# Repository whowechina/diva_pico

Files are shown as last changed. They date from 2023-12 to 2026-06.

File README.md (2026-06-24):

# Diva Pico - Project Diva Style Mini Controller
[点这里可以切换到中文版](README_CN.md)

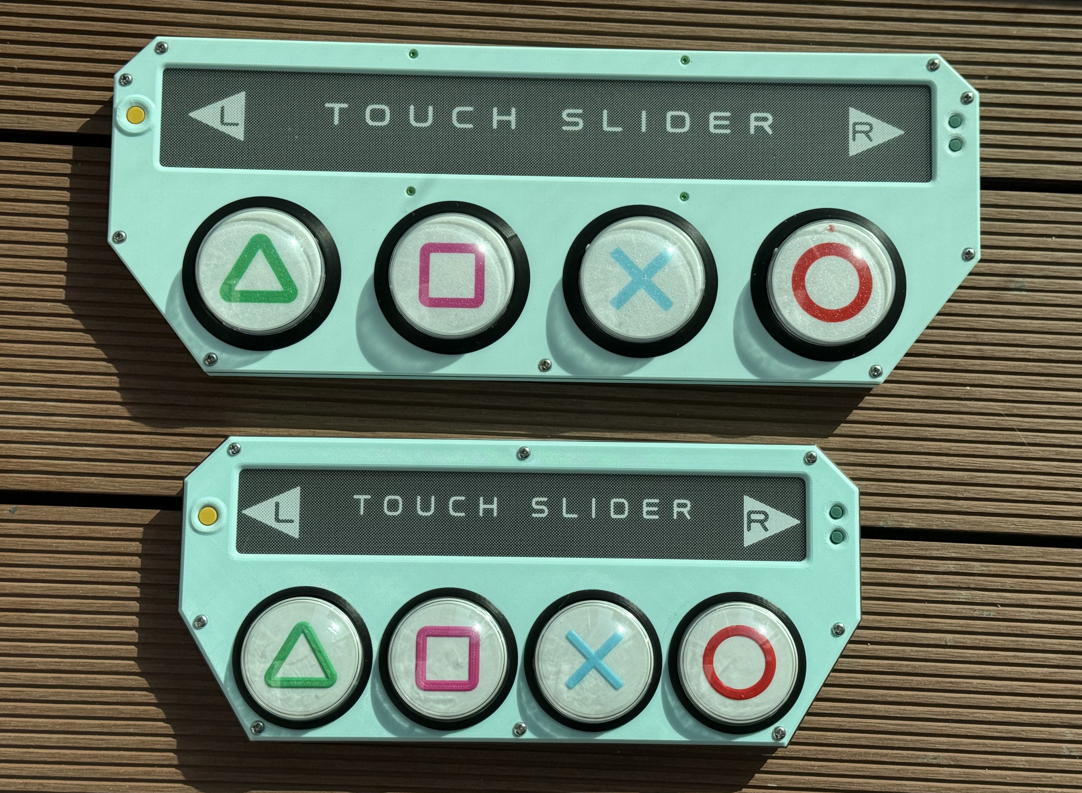
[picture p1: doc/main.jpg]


Features:
* Two sizes, Diva Pico and Diva Pico+.
* It's small, but the buttons are still decent.
* Support Nintendo Switch, Steam PC and Arcade version.
* HID light for Arcade version.
* All source files open.

Thanks to many respectful guys/companies who made their tools or materials free or open source (KiCad, OnShape, InkScape, Raspberry things).

Special thanks to community developers that inspired me and helped me: CrazyRedMachine (https://github.com/CrazyRedMachine).

And also:
* GP2040-CE: https://gp2040-ce.info/ (for the PS4 support)
* RP_Silicon_KiCad: https://github.com/HeadBoffin/RP_Silicon_KiCad
* Switch_Keyboard_Kailh: https://github.com/kiswitch/keyswitch-kicad-library

## Notes
This Diva Pico project:  
* Heavily depends on 3D printing, you need a Bambu 3D printer (X1, P1 or A1, not the mini version).
* Requires skills to solder tiny components.

## My Other Projects
You can check out my other cool projects.

               


* Popn Pico: https://github.com/whowechina/popn_pico
* IIDX Pico: https://github.com/whowechina/iidx_pico
* Chu Pico: https://github.com/whowechina/chu_pico
* Mai Pico: https://github.com/whowechina/mai_pico
* Diva Pico: https://github.com/whowechina/diva_pico
* AIC Pico: https://github.com/whowechina/aic_pico
* Groove Pico: https://github.com/whowechina/groove_pico
* Geki Pico: https://github.com/whowechina/geki_pico
* Musec Pico: https://github.com/whowechina/musec_pico
* Ju Pico: https://github.com/whowechina/ju_pico
* Bishi Pico: https://github.com/whowechina/bishi_pico
* Nos Pico: https://github.com/whowechina/nos_pico
* Voltex Pico: https://github.com/whowechina/voltex_pico
* Chord Pico: https://github.com/whowechina/chord_pico
* Dance Pico: https://github.com/whowechina/dance_pico
* Arcade Pico: https://github.com/whowechina/arcade_pico

## **Disclaimer** ##
I made this project in my personal time with no financial benefit or sponsorship. I will continue to improve the project. I have done my best to ensure that everything is accurate and functional, there's always a chance that mistakes may occur. I cannot be held responsible for any loss of your time or money that may result from using this open source project. Thank you for your understanding.

## About the License
It's CC-NC. So DIY for yourself and for your friend, don't make money from it. And plagiarism that doesn’t even dare to mention the original author is not acceptable. Plase note that pooling orders and group buying for raw materials is acceptable. Selling off any leftover components without profit is also acceptable.

If you're interested in some kind of commercial use, please contact me (Discord, QQ group, Wechat group or leave your contact in issue section).

## My Discord Invitation
https://discord.gg/M8f2PPQFEA

## HOW TO BUILD
### Frequently Made Mistakes
Many DIY enthusiasts commonly make certain mistakes during the building process. Please proceed with extra caution to avoid these.
* **MISTAKE: Soldering everything together without conducting intermediate testing.**  
  Remember, even professional engineers can make mistakes. It becomes significantly harder to identify the root cause of a problem when all components are already assembled or soldered. Therefore, it's advisable to solder and test in stages. The firmware is designed to function correctly even with some components missing, which is good for testing.
* **MISTAKE: Neglecting to cut the ADDR pin trace on the MPR121 module.**  
  The MPR121 module in the market has the ADDR pin pre-connected to ground. But the board expects a floating ADDR pin, otherwise the ADDR pin will short the circuit. Please verify your "CUT" using a multimeter.
* **MISTAKE: Rushing to replace components when something fails.**  
  Sometimes people prematurely assumes that the Raspberry Pi Pico or other modules are faulty.
  Be aware that desoldering and soldering large SMD components is a challenging task. It carries the risk of damaging the component or the PCB board. Patience and caution are crucial. Look at the schematics and PCB design files and ask help from community first. Questioning the integrity of these components should be your last resort.

### PCB
* Choose a PCB vendor (such as JLCPCB) and place an order with the gerber zip file (latest `Production\PCB\diva_xxx_xxx.zip`), regular FR-4 board, black color, thickness is **1.6mm**.  
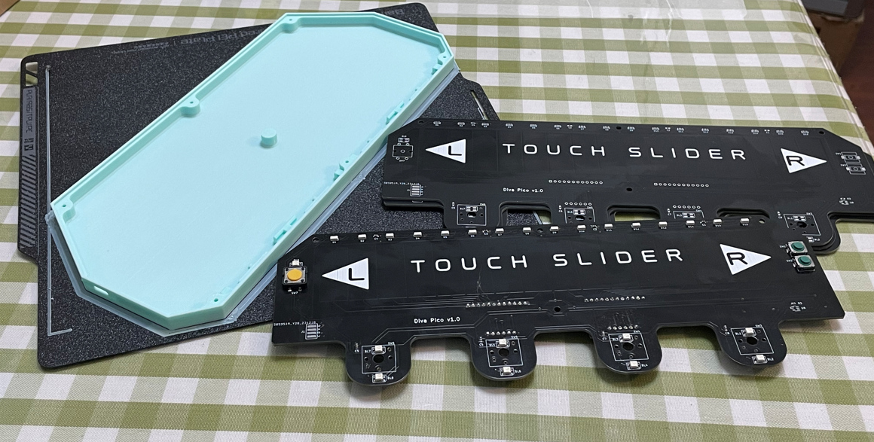
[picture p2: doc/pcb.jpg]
  

* 1x Rasberry Pico Pi Pico or **pin-to-pin** compatible clones.  
  https://www.raspberrypi.com/products/raspberry-pi-pico  
  Sticking a thin scotch tape to avoid short-circuit is a good idea.  
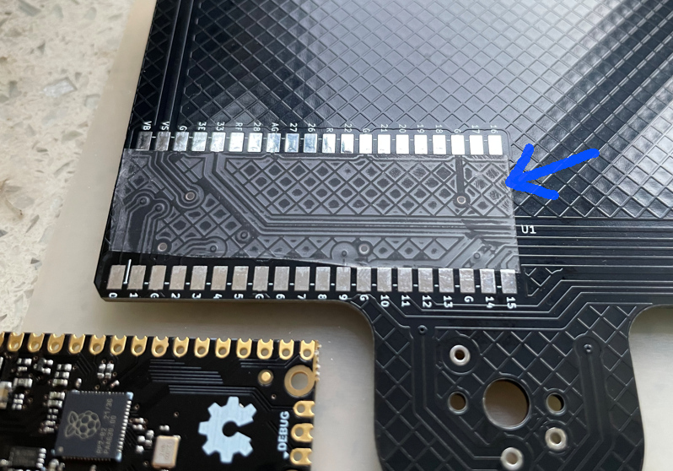
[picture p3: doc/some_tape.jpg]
  

* 16x WS2812B-4020 (32x for Diva Pico+) side-facing RGB LEDs for the slider.  
  https://www.lcsc.com/product-detail/Light-Emitting-Diodes-LED_Worldsemi-WS2812B-4020_C965557.html
* 9x WS2812B-3528 RGB LEDs for Diva Pico buttons. For Diva Pico+, you need 17x WS2812B-3528 reverse mount RGB LEDs.

* 2x MPR121 modules (3x for Diva Pico+), there're many types in the market, choose ones like this.  
  https://www.sparkfun.com/products/retired/9695  
  Before solder MP121 module to the main PCB board, remember to use a knife to **cut (unshort) the tiny trace that connects ADDR to the GND**. You can cut the red part as shown in the image. Please be careful not to cut more than necessary.  
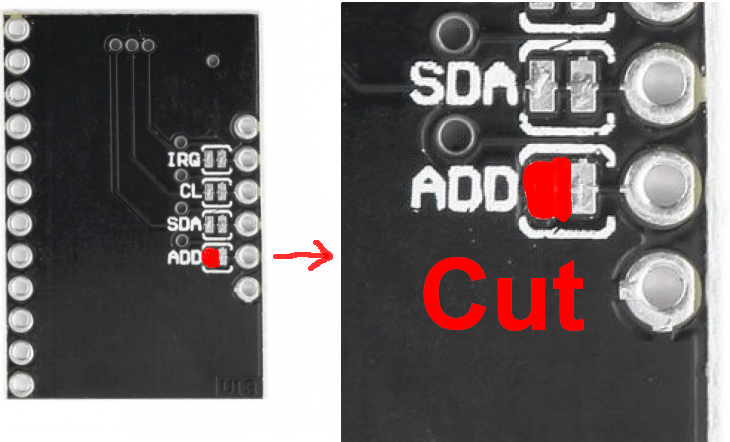
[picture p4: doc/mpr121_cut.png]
    

* 8x 0603 1uF (0.1~1uF all fine) capacitors (C1 to C8), OPTIONAL, recommended.

* 4x Kailh choc v1 switches, dark yellow is recommeded for its 70gf force.  
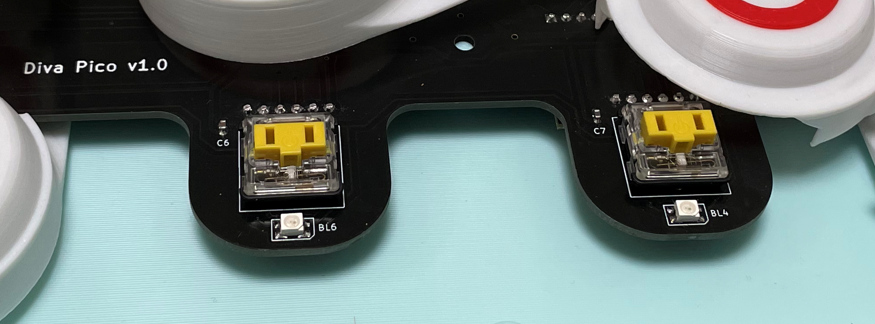
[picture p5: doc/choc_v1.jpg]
  

* 2x Alps SKSTAAE010 tactile switches.
  https://tech.alpsalpine.com/e/products/detail/SKSTAAE010/

* 1x Omron B3F-4005 or B3F-4000 micro-switch.
  https://www.mouser.com/ProductDetail/Omron-Electronics/B3F-4000?qs=B3tblJ0Nlt8c5sbFRctxww%3D%3D

* For Diva Pico only, 3M 5423 or 5421 UHMW PE film tape, important for button feel. 5423 is better for its thickness.  
  https://www.3m.com/3M/en_US/p/d/b40069119/

  You need to apply tapes to the contact surface of button to switch and button to base clamp.  
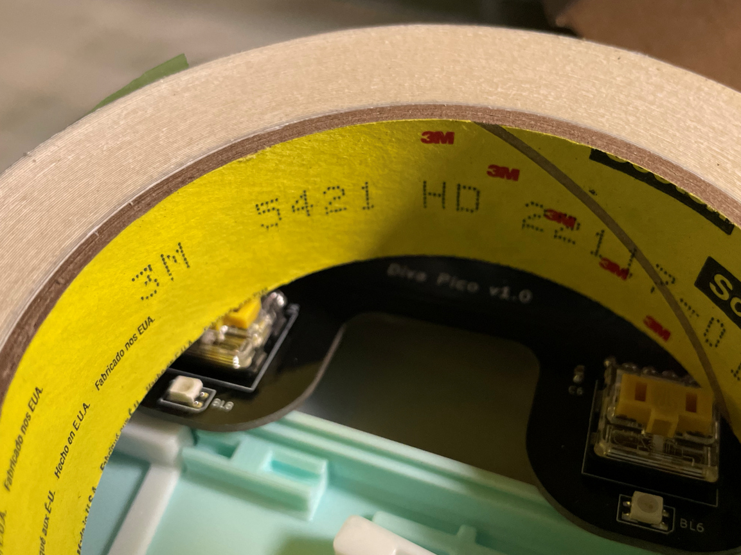
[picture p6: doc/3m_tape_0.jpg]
  
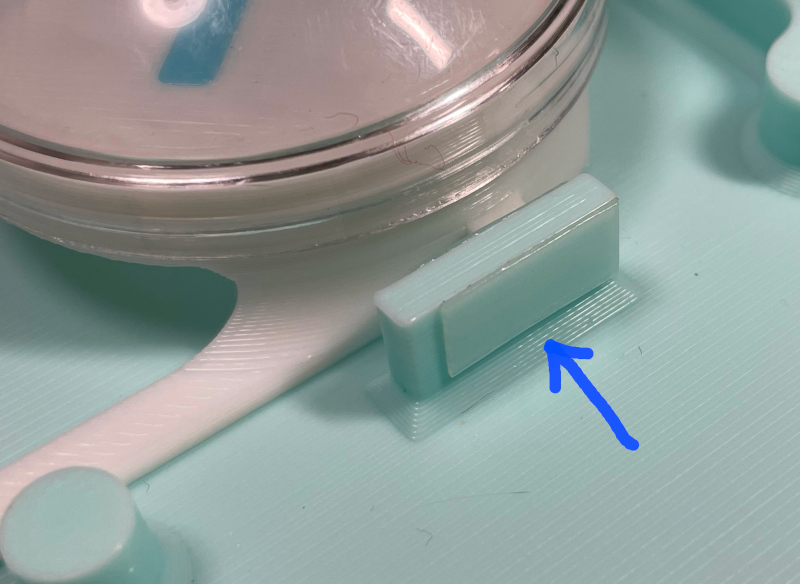
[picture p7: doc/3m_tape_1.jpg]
  
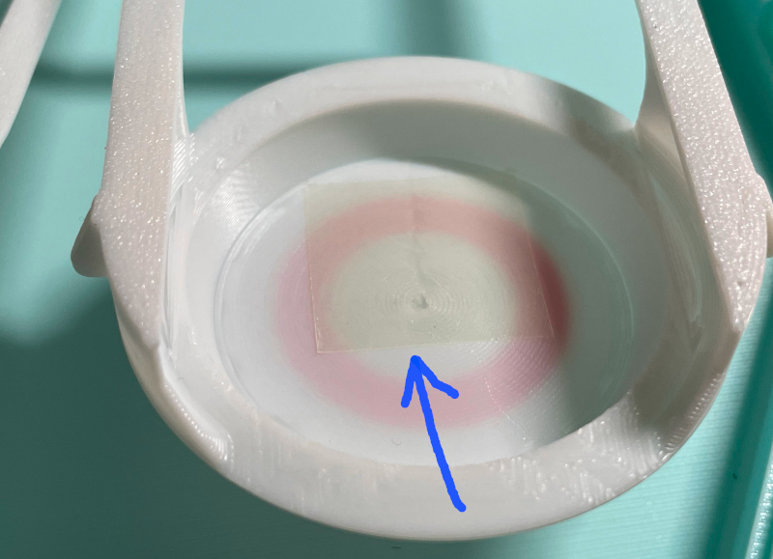
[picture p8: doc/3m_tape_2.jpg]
  

* For Diva Pico only, 4x 2mm\*50mm (diameter\*length) steel rods for the button lever structure.

* For Diva Pico+ only, 8x U-shape 2U stabilizer steel wires, you can also harvest them from regular 2U MX stabilizers. I invented this structure originally in my Voltex Pico project, checkout Voltex Pico repository for more details.

* For Diva Pico+ only, 4x 3mm\*5mm\*10mm regular springs for increasing the button force.

### Light Guide Panel
* Find a service to cut a light guide panel or a frosted acrylic panel. It's a perfect rectangle, 1.8mm to 2.0mm thickness
  * For Diva Pico, the size is 240mm\*42mm.
  * For Diva Pico+, the size is 329mm\*47mm.
* This is what a decent light guide panel looks like.  
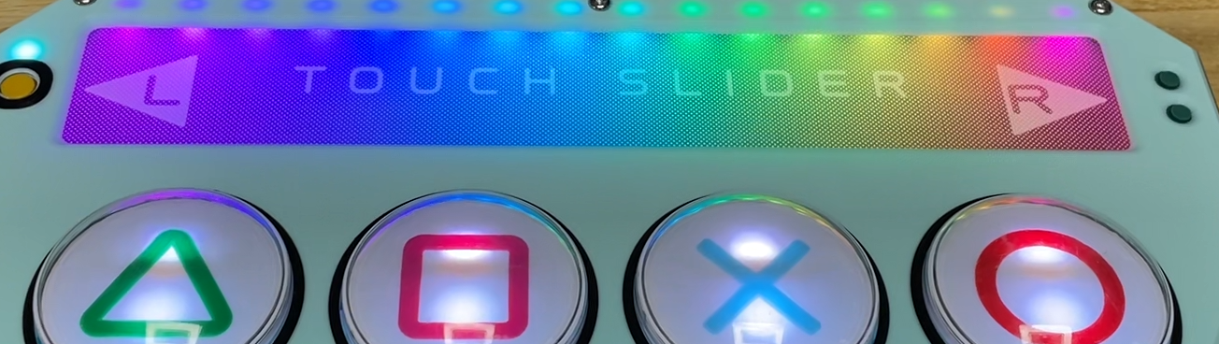
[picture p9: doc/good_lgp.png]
  

### 3D Printing
* You might need a Bambu 3D printer:
  *  For Diva Pico, a 256\*256mm bed is fine; for Diva Pico+ you need a H2D-sized bed.
  * Its AMS system works great for multi-color printing.
* Printing parameters  
  * PLA, PETG, ABS are all OK.
  * The color "Arctic Whisper" works best for the main body.
  * Layer height: 0.2mm
  * Support: Yes, always.

* Base: `Production\3D\diva_xxx_base.stl`.
* Cover Base: `Production\3D\diva_xxx_support.stl`.
* Cover: `Production\3D\diva_xxx_panel.3mf`, with multi-color support.
* Buttons: `Production\3D\diva_xxx_button_combo.3mf`, with multi-color support.  
  Note that button components (the button body, the seat and the logos on it) are mixed in one file, you need to cherry-pick before printing.  
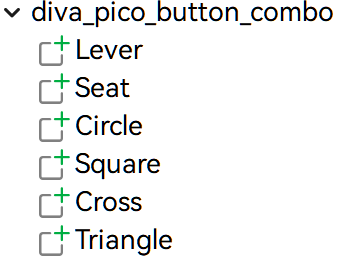
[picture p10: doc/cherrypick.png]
  

From top to bottom:
* Cover
* Cover Base + Light Guide Panel
* Buttons
* PCB
* Base

For Diva Pico, you need **6x M3*10mm regular screws** to fix all things. For Diva Pico+, you need **9x M3\*8mm** regular screws and **4x M2\*8mm** flat head screws.

Apply some 10mm\*2mm silicone anti-slip pads to the bottom side of the base to provide stability when playing.  

#### Button dome choices
* Go buy 60mm dome buttons.
  * For Diva Pico+, a regular 60mm arcade dome button is fine.
  * For Diva Pico, you should get this specific one, its inner diameter is 46mm.  
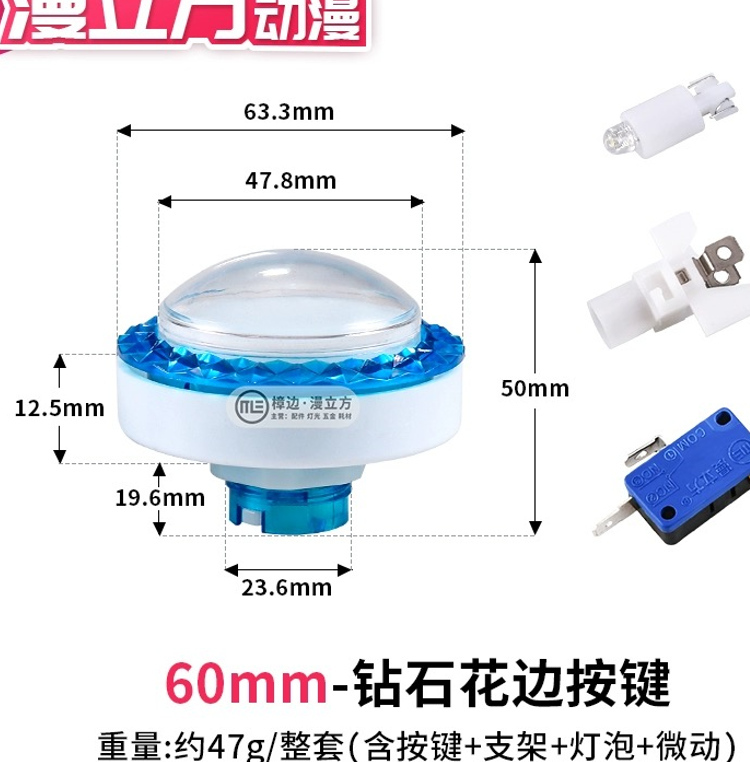
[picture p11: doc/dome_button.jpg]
    

### Firmware
* UF2 file is in `Production\Firmware` folder.
* For the new build, hold the BOOTSEL button while connect the USB to a PC, there will be a disk named "RPI-RP2" showed up. Drag the UF2 firmware binary file into it. That's it. There's a small hole at the bottom side of the Diva Pico, it is facing right to the BOOTSEL button.
* It has a command line to do configuration. You can use this Web Serial Terminal to connect to the USB serial port of the Diva Pico. (Note: "?" is for help)  
  https://googlechromelabs.github.io/serial-terminal/  
* You can switch key mapping mode using either of the following methods:
  * Hold Triangle, Square, Cross, Circle or Cross+Circle while plugging in the USB cable to switch to Nintendo Switch, PC Steam, Arcade, PlayStation and PlayStation Arcade mode, respectively.
  * Use the `keymap` command in the command line interface.
* In Nintendo Switch, PC Steam, and PlayStation modes, the left auxiliary button is used as a "SHIFT" key, changing the functions of the other six buttons.
* In PlayStation mode, if key-related files are missing, the console will disconnect controller input after 8 minutes. You can use the following tool to set a PS key.  
  https://whowechina.github.io/diva_pico/tools/ps4key_packer.html
  * **Note** The Diva Pico project will not provide any files or information related to acquiring these files. Do not request them through any communication channel (e.g., Email, Instant Messaging, GitHub Issues, Discord).

## CAD Source File
I'm using OnShape free subscription. It's powerful but it can't archive original designs to local, so I can only share the link here. STL/DXF/DWG files are exported from this online document.  
https://cad.onshape.com/documents/d9e9c1de2d4b98d5eaf21d07/w/7c216f367b558e083eb1f468/e/4536bf9859137db81313ff87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

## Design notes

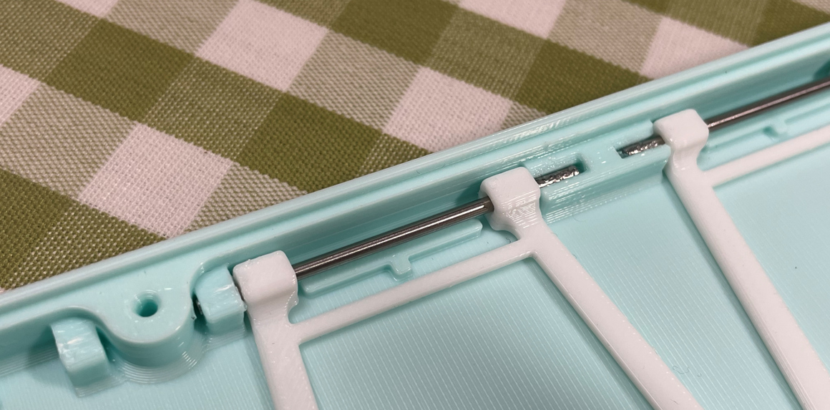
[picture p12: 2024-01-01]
doc/rotating_hinge.jpg

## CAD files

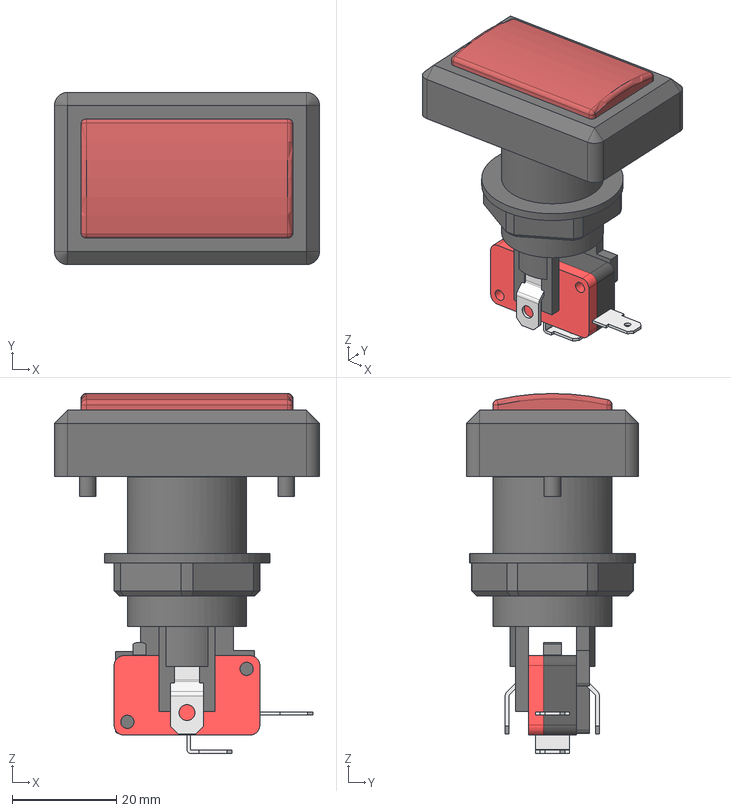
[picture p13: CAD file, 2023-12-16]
PCB/plus/3dmodels/Credit Button Assy (Groovy).step
50.8 x 33.0 x 69.0 mm
Button
Nut
Switch

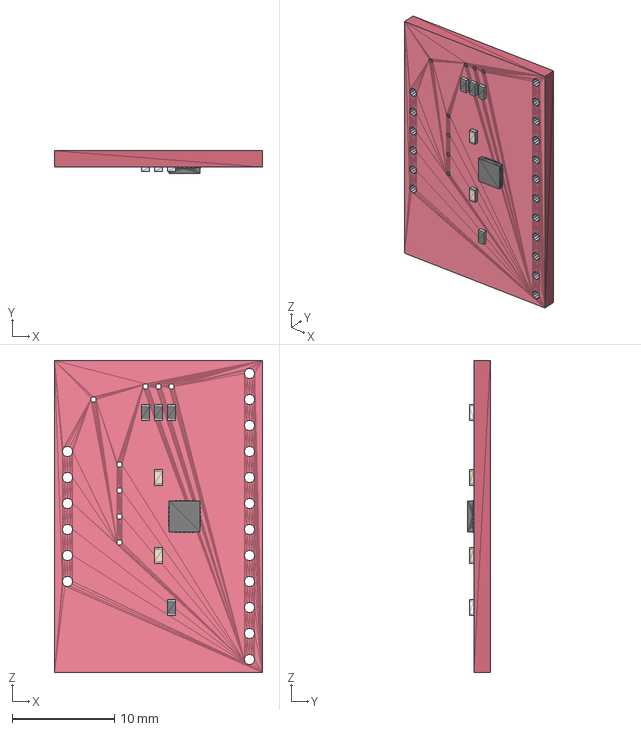
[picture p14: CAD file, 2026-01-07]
PCB/plus/3dmodels/mpr121_breakout_v13.step
20.3 x 2.20 x 30.5 mm

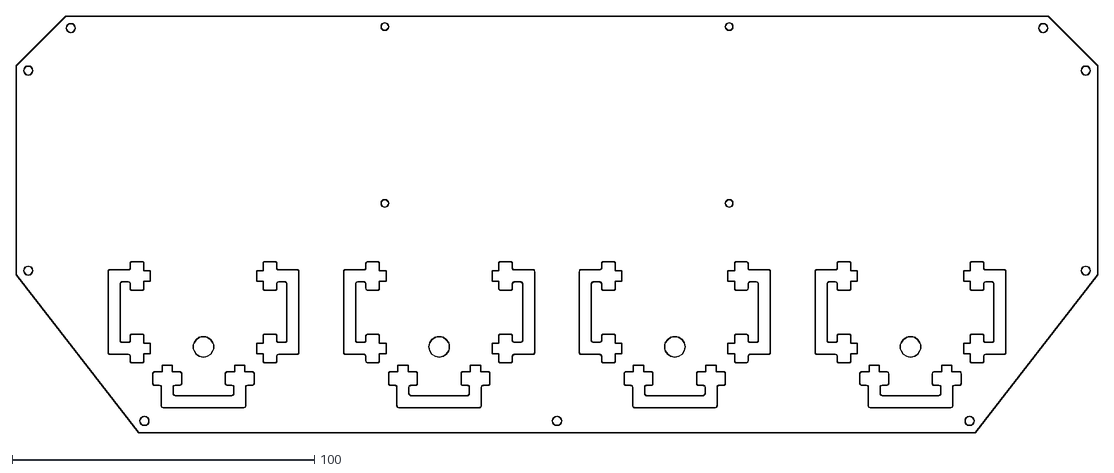
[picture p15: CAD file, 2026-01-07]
PCB/plus/Diva Pico+ - PCB EdgeCut.dxf
357.8 x 137.8

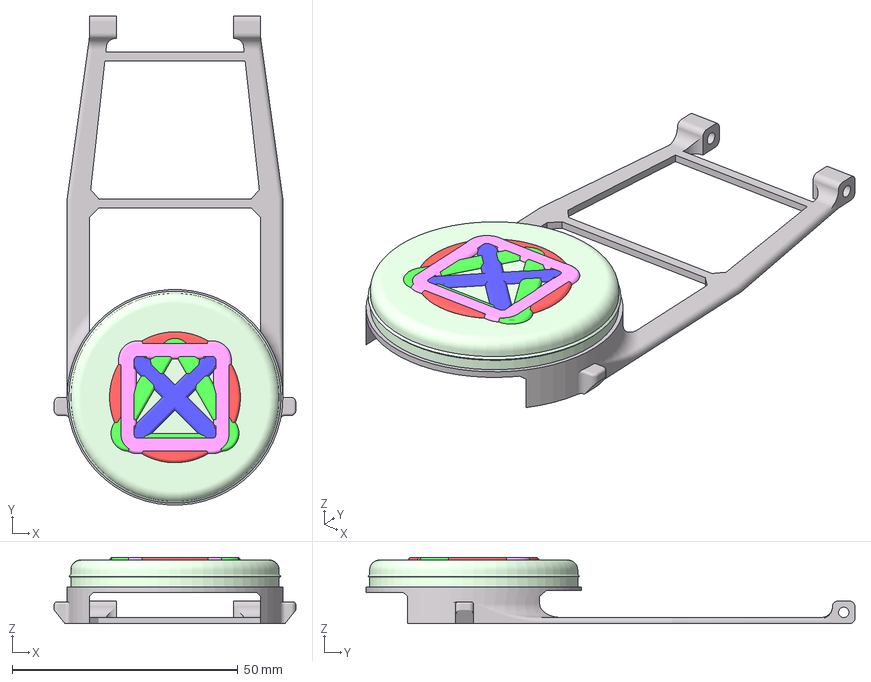
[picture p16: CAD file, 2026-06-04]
Production/CAD/diva_pico_button_combo.3mf
53.5 x 108.4 x 14.7 mm
Circle
Seat
Lever
Square
Cross
Triangle

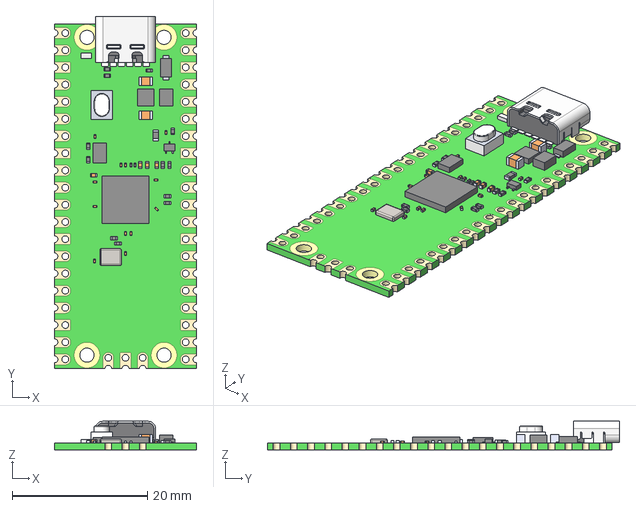
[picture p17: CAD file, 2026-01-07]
PCB/plus/3dmodels/Pi Pico Type-C.step
21.0 x 52.1 x 4.22 mm

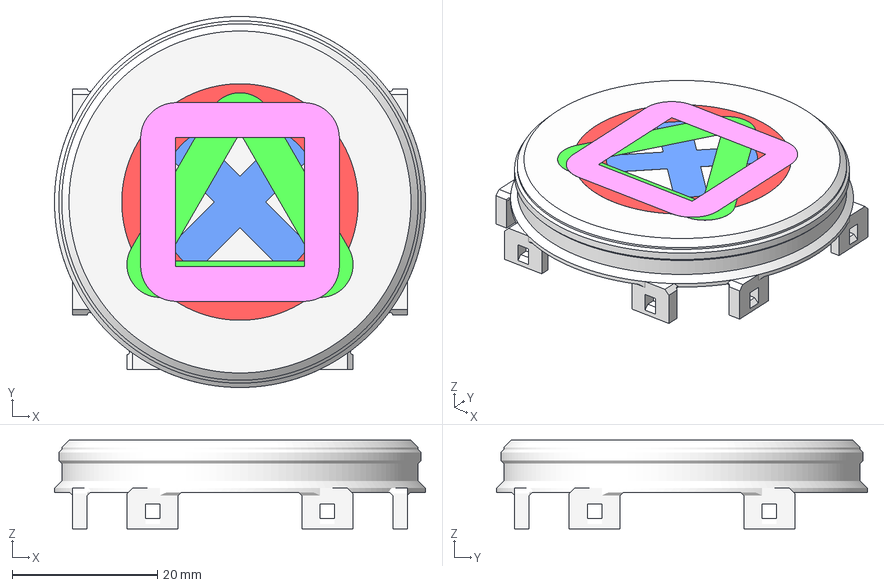
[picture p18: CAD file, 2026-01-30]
Production/CAD/Button+_Choc_V2_Combo.3mf
51.0 x 51.0 x 12.2 mm
Cross+
Seat
Circle+
Square+
Triangle+

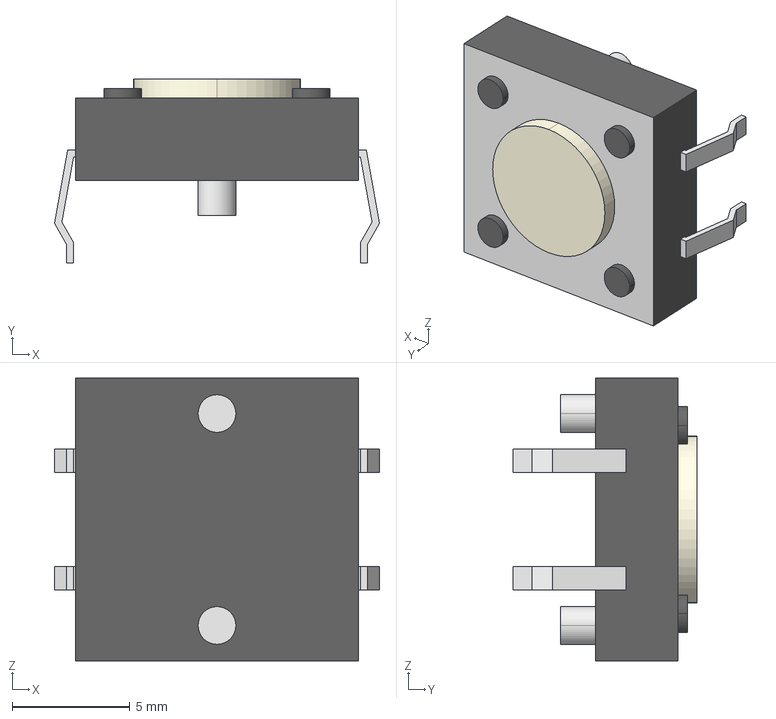
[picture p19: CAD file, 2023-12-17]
PCB/plus/3dmodels/b3f-4000.stp
13.8 x 7.80 x 12.0 mm

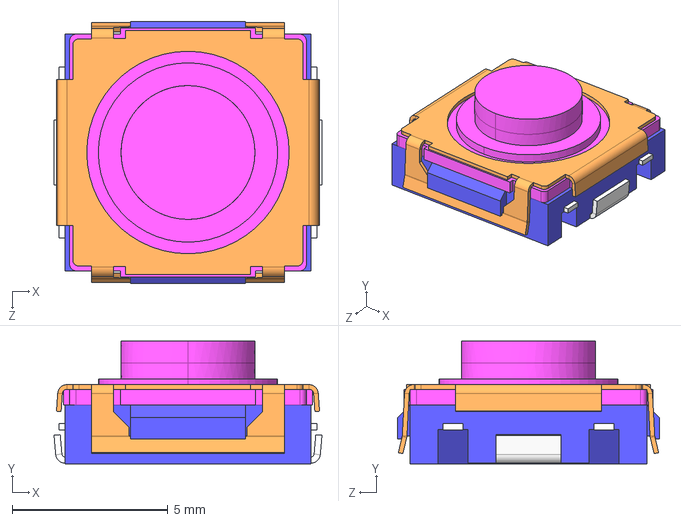
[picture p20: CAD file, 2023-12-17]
PCB/plus/3dmodels/SKSTAAE010.STEP
8.61 x 3.95 x 8.40 mm

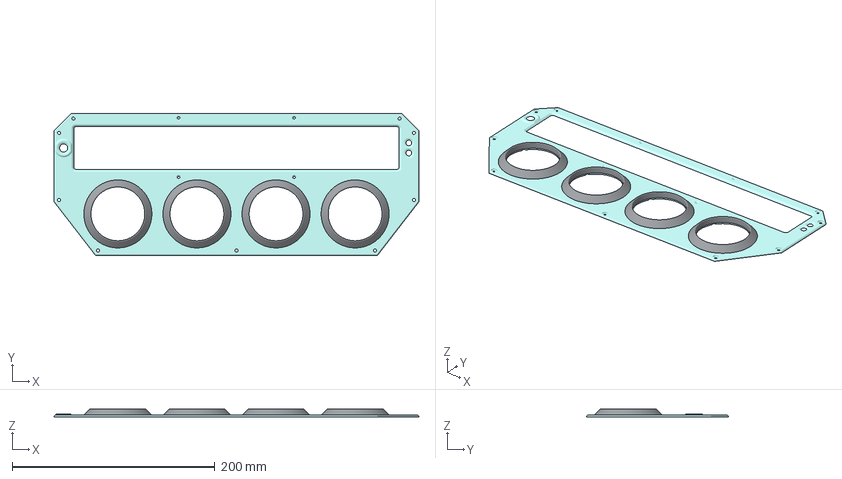
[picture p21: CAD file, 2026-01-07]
Production/CAD/Diva Pico+ - Panel Combo.3mf
360.0 x 140.0 x 8.00 mm
Panel
Ring 1
Ring 2
Ring 3
Ring 4

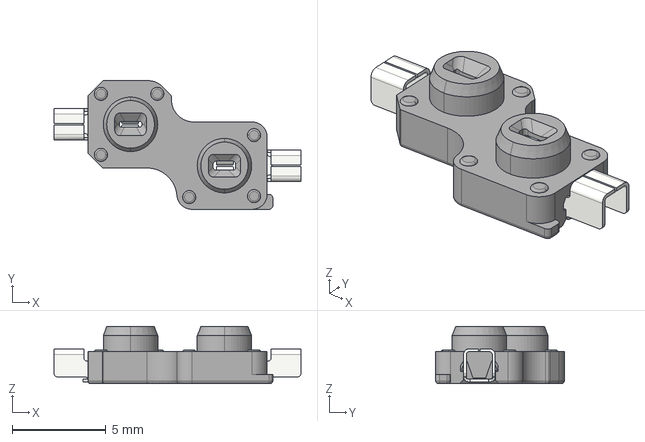
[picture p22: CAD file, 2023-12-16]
PCB/plus/3dmodels/SW_Hotswap_Kailh_Choc_V1.stp
13.2 x 6.85 x 3.05 mm

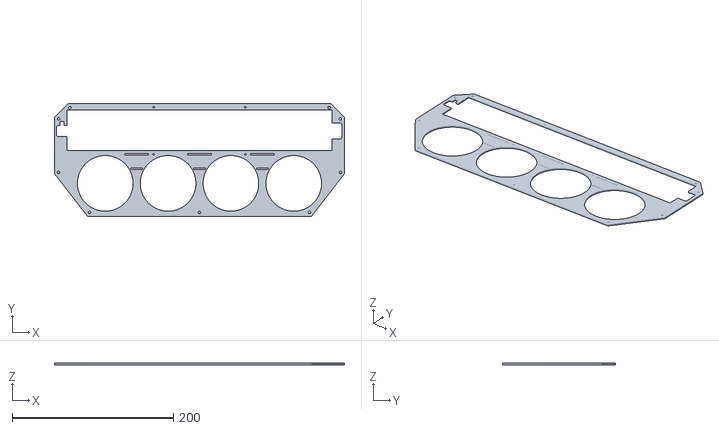
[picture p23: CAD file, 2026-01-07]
Production/CAD/Diva Pico+ - Support.stl
360.0 x 140.0 x 2.00

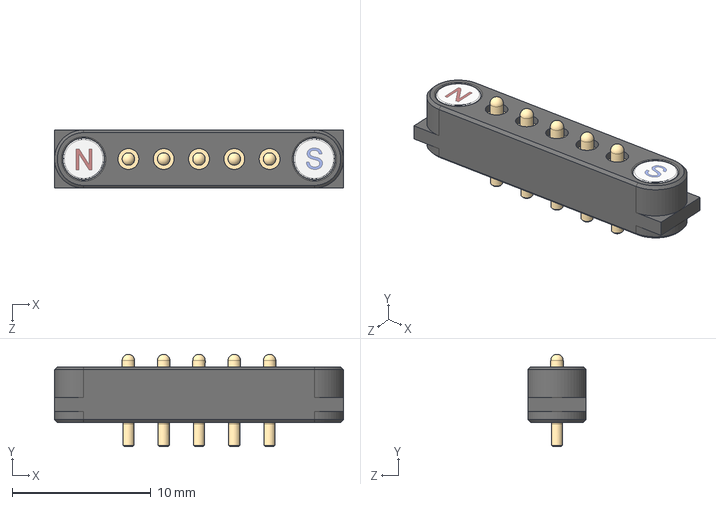
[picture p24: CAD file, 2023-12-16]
PCB/plus/3dmodels/Magnetic Pogo Connector 5 Pin (Type 2).STEP
20.8 x 6.65 x 4.20 mm

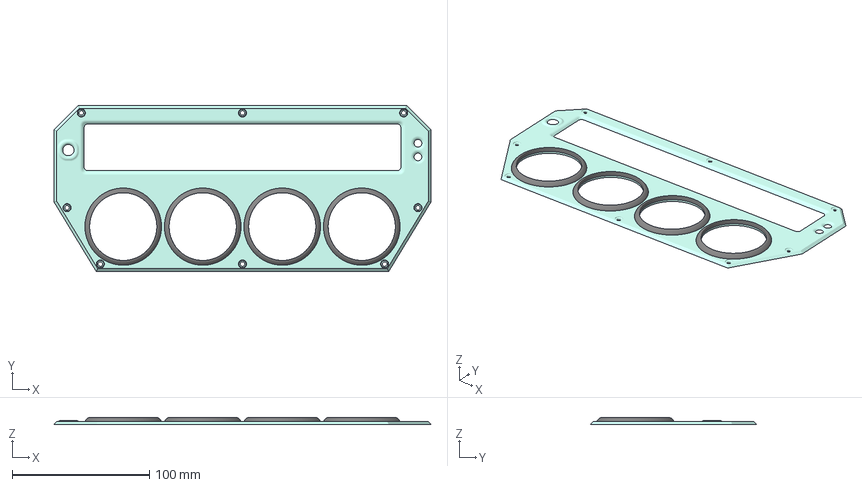
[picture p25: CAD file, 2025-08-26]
Production/CAD/diva_pico_panel.3mf
275.0 x 121.0 x 5.00 mm
Panel
Ring1
Ring2
Ring3
Ring4

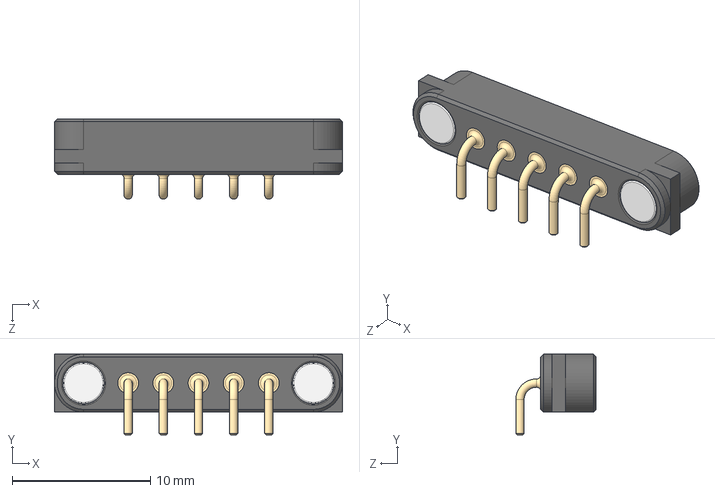
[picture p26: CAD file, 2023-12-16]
PCB/plus/3dmodels/Magnetic Pogo Connector 5 Pin (Type 3).STEP
20.8 x 5.85 x 5.80 mm

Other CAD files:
PCB/plus/3dmodels/iidx_keycap_main_step.stp
Production/CAD/diva_pico_base.stl
PCB/plus/3dmodels/SW_Kailh_Choc_V1.stp
PCB/plus/3dmodels/WS2812B.step
PCB/plus/3dmodels/gp2y0e03.scad
PCB/plus/3dmodels/keypad_lgp.scad
PCB/plus/3dmodels/EVQ-P1D05M.stp
PCB/plus/3dmodels/J 2835.step
PCB/plus/3dmodels/Kailh LP Choc PC Keycap.step
PCB/plus/3dmodels/Magnetic Pogo Connector 5 Pin (F).STEP
PCB/plus/3dmodels/Magnetic Pogo Connector 5 Pin (Type 1).STEP
PCB/plus/3dmodels/Magnetic Pogo Connector 5 Pin (Type 4).STEP
PCB/plus/3dmodels/SKPMAM.STEP
PCB/plus/3dmodels/SMD WS2812B-3535.step
PCB/plus/3dmodels/SW_Hotswap_Kailh_MX.stp
PCB/plus/3dmodels/Tact Switch 4.5mm SMT.step
PCB/plus/3dmodels/User Library-PTS645SL95SMTR92-LFS.STEP
PCB/plus/3dmodels/User Library-WS2812-2020.step
PCB/plus/3dmodels/User Library-WS2812-4020.step
PCB/plus/3dmodels/User Library-pj-393-8.STEP
PCB/plus/3dmodels/WS2812-0807.STEP
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

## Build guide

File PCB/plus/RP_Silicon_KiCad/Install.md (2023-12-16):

# Install KiCad libraries

## Manage Symbol Libraries

Accessed from the Preferences menu, add a new line with the +, give it a name and use the folder icon to point to the directory/folder where you have KiCadLibraries.

Manage Symbol Libraries screen shot


## Manage Footprint Libraries

Ditto! Accessed from the Preferences menu, add a new line with the +, give it a name and use the folder icon to point to the directory/folder where you have KiCadLibraries.

Manage Footprint Libraries screen shot


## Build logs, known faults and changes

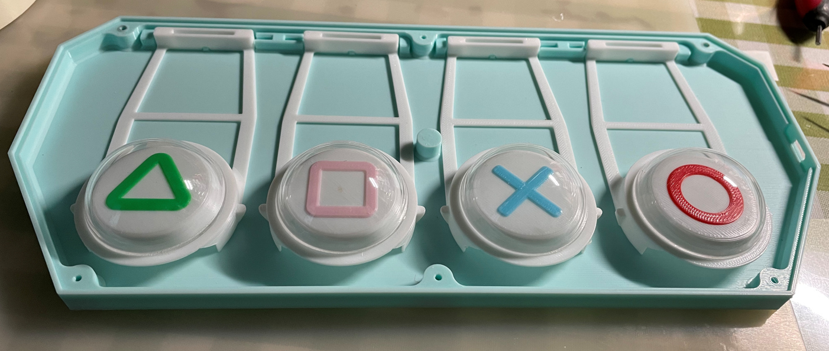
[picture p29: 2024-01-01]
doc/fix_hinge.jpg

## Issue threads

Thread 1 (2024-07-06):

Cover base file and base file's thickness is 0mm on JLC3DP

haneu123, 2024-07-06:
English:
Hello, I tried to import the cover base file and base into 3D Monkey (Jialichuang 3D Printing), but it shows that the thickness of these two files is 0mm and cannot be used . Does this model file need to be used for printing with Bambu 3D printer?
Looking forward to your reply, my English is not very good. Thank you so much.

Simplified Chinese:
大佬你好，我尝试把cover base文件和base导入三维猴（嘉立创3D打印），但是上面显示这两个文件的厚度均为0mm，无法用于打印。请问是不是这个模型文件需要用拓竹3D打印机才能用于打印。
期待大佬的回复，英语不太好，谢谢了。

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

whowechina, 2024-07-06:
我试了一下，似乎它有最小壁厚太薄的提醒，点开来有“接受风险下单“和”咨询客服“的选项，你问问它们客服看。
这个文件没有限定是什么打印机，只要够大，且是 0.4mm 喷头，PLA/PETG 都没问题。
注意打印时底部不能翘边，翘边就作废了。

Closed 2024-07-07.

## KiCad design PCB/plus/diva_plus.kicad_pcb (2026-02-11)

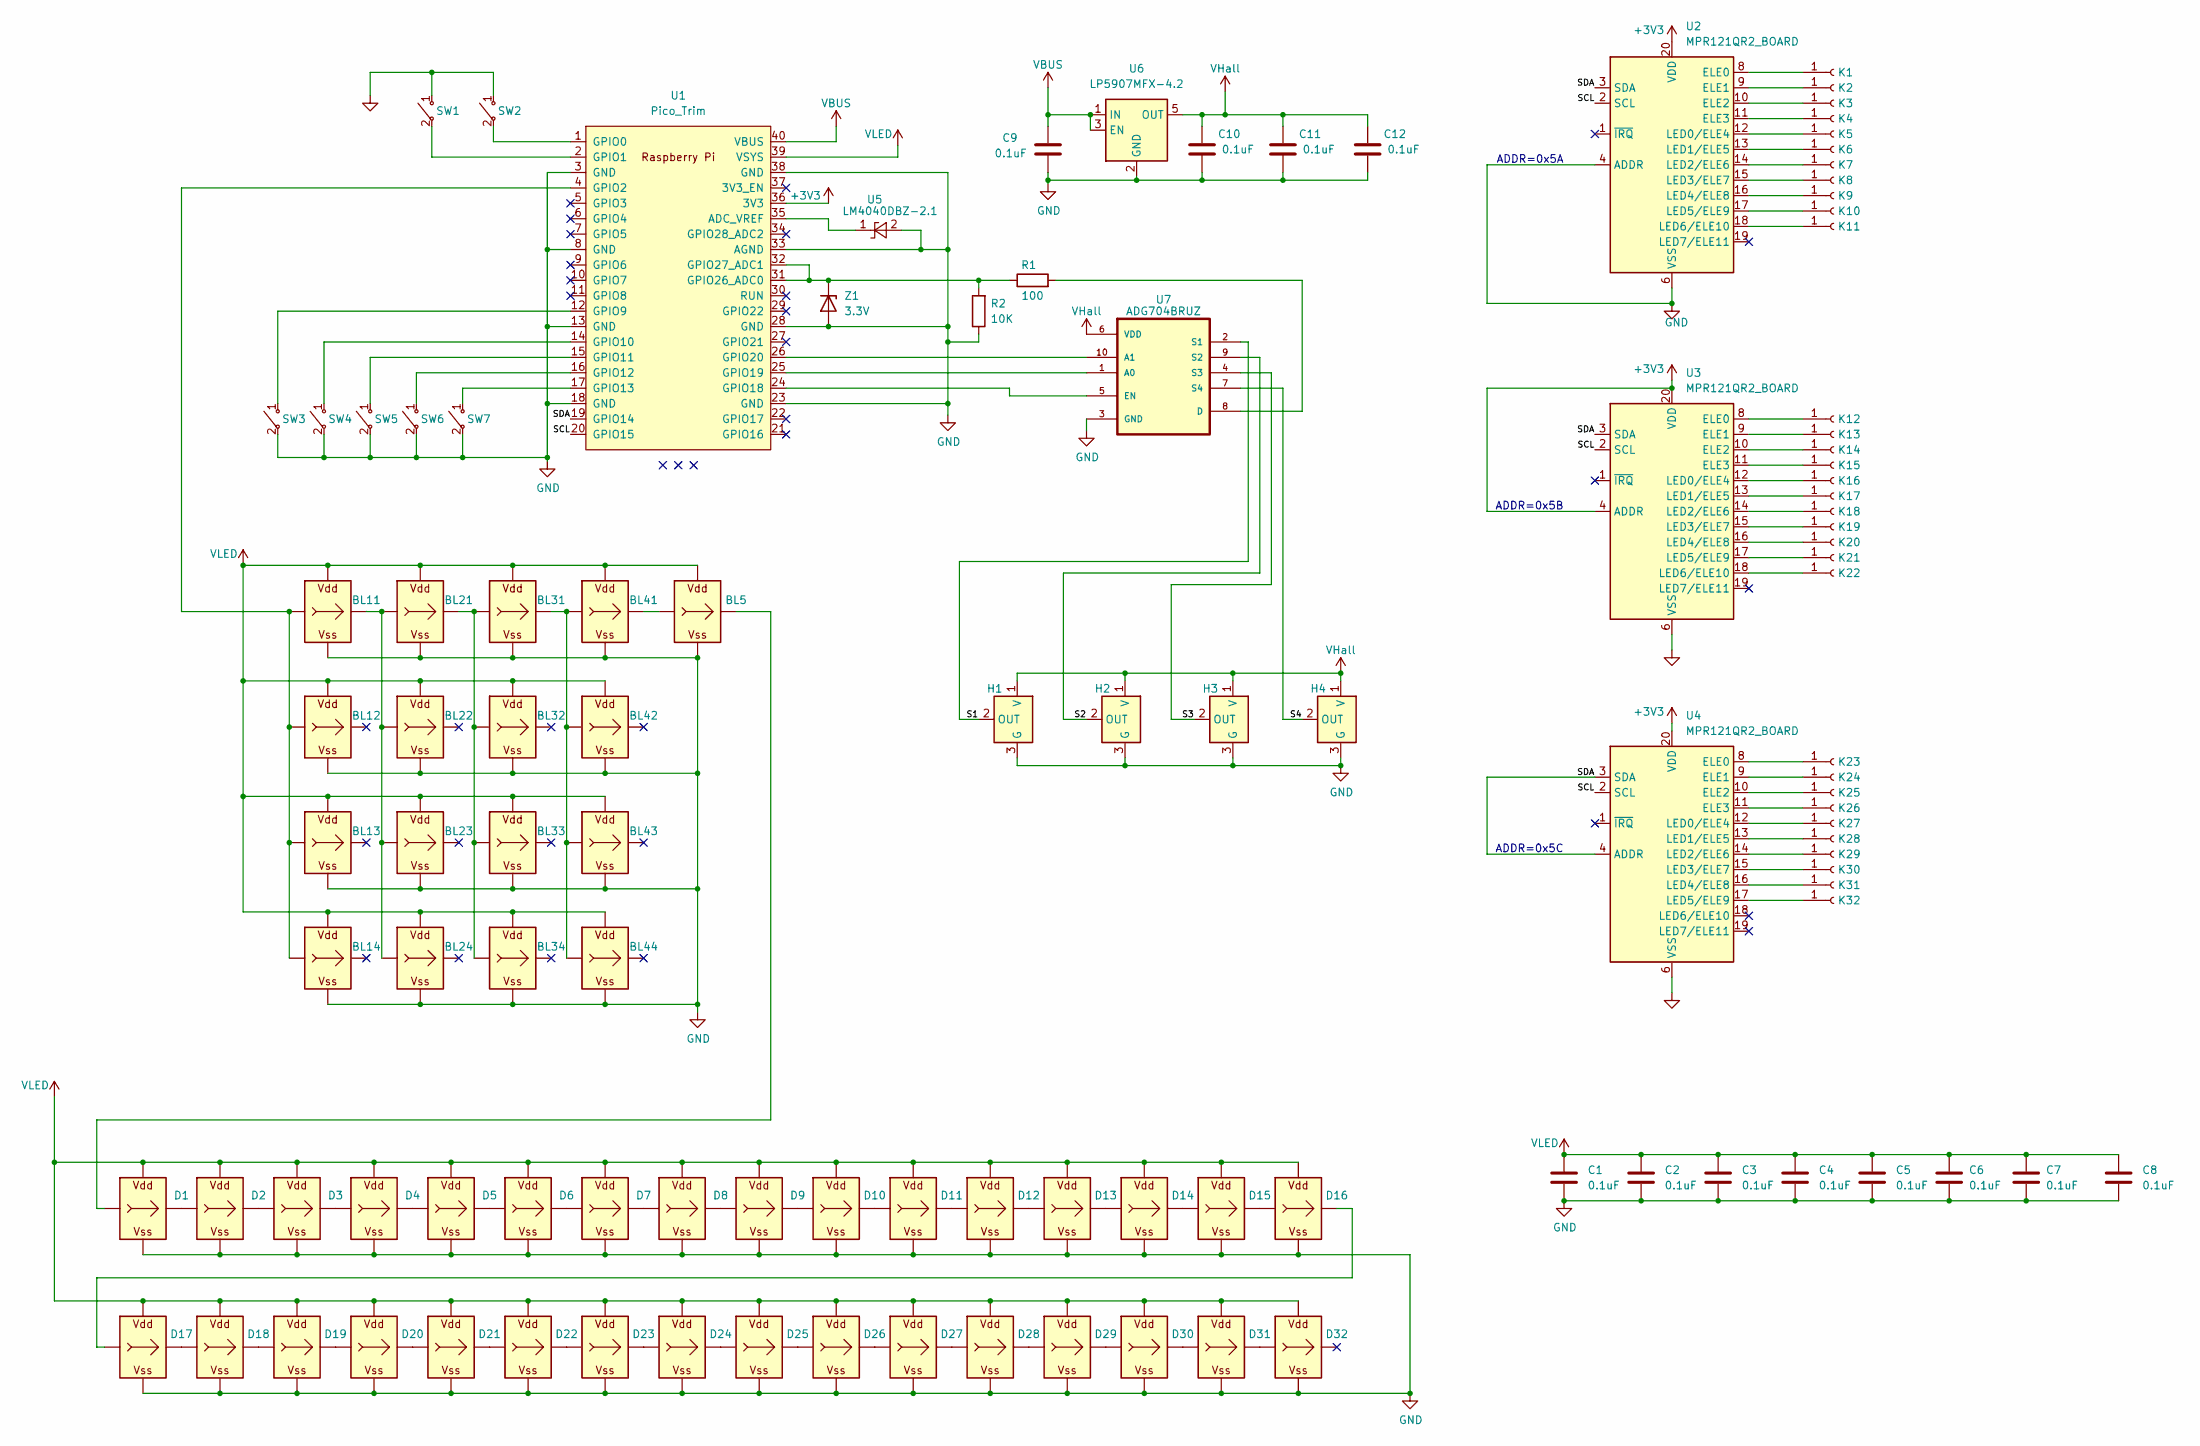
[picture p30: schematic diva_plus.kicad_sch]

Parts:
BL5, BL11, BL12, BL13, BL14, BL21, BL22, BL23, BL24, BL31, BL32, BL33, BL34, BL41, BL42, BL43, BL44: WS2812B_Unified; WS2812B-2835_EMBED
C1, C2, C3, C4, C5, C6, C7, C8, C9, C10, C11, C12: 0.1uF; C_0603_1608Metric_Pad1.08x0.95mm_HandSolder
D1, D2, D3, D4, D5, D6, D7, D8, D9, D10, D11, D12, D13, D14, D15, D16, D17, D18, D19, D20, D21, D22, D23, D24, D25, D26, D27, D28, D29, D30, D31, D32: WS2812B_Unified; WS2812B-4020
H1, H2, H3, H4: SS49E_SOT23; SOT-23-FAT
K1, K2, K3, K4, K5, K6, K7, K8, K9, K10, K13, K14, K15, K16, K18, K19, K20, K21, K24, K25, K26, K27, K28, K29, K30, K31, K32: Conn_01x01_Female; DivaKey
K11, K22: Conn_01x01_Female; DivaKeyBiasLeft
K12, K17, K23: Conn_01x01_Female; DivaKeyBiasRight
R1: 100; R_0603_1608Metric_Pad0.98x0.95mm_HandSolder
R2: 10K; R_0603_1608Metric_Pad0.98x0.95mm_HandSolder
SW1, SW2: SWITCH_SPST; SKSTAAE010
SW3, SW4, SW5, SW6: SWITCH_SPST; Choc_HE
SW7: SWITCH_SPST; B3F4000
U1: Pico_Trim; RPi_Pico_SMD_No_USB
U2, U3, U4: MPR121QR2_BOARD; MPR121_BOARD
U5: LM4040DBZ-2.1; SOT-23-FAT
U6: LP5907MFX-4.2; SOT-23-5
U7: ADG704BRUZ; TSSOP-10_3x3mm_P0.5mm
Z1: 3.3V; D_SOD-123F

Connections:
+3V3: U1.36 (3V3), U2.20 (VDD), U3.4 (ADDR), U3.20 (VDD), U4.20 (VDD)
/S1: H1.2 (OUT), U7.2 (S1)
/S2: H2.2 (OUT), U7.9 (S2)
/S3: H3.2 (OUT), U7.4 (S3)
/S4: H4.2 (OUT), U7.7 (S4)
/SCL: U1.20 (GPIO15), U2.2 (SCL), U3.2 (SCL), U4.2 (SCL)
/SDA: U1.19 (GPIO14), U2.3 (SDA), U3.3 (SDA), U4.3 (SDA), U4.4 (ADDR)
GND: BL5.G (VSS), BL11.G (VSS), BL12.G (VSS), BL13.G (VSS), BL14.G (VSS), BL21.G (VSS), BL22.G (VSS), BL23.G (VSS), BL24.G (VSS), BL31.G (VSS), BL32.G (VSS), BL33.G (VSS), BL34.G (VSS), BL41.G (VSS), BL42.G (VSS), BL43.G (VSS), BL44.G (VSS), C1.2, C2.2, C3.2, C4.2, C5.2, C6.2, C7.2, C8.2, C9.2, C10.2, C11.2, C12.2, D1.G (VSS), D2.G (VSS), D3.G (VSS), D4.G (VSS), D5.G (VSS), D6.G (VSS), D7.G (VSS), D8.G (VSS), D9.G (VSS), D10.G (VSS), D11.G (VSS), D12.G (VSS), D13.G (VSS), D14.G (VSS), D15.G (VSS), D16.G (VSS), D17.G (VSS), D18.G (VSS), D19.G (VSS), D20.G (VSS), D21.G (VSS), D22.G (VSS), D23.G (VSS), D24.G (VSS), D25.G (VSS), D26.G (VSS), D27.G (VSS), D28.G (VSS), D29.G (VSS), D30.G (VSS), D31.G (VSS), D32.G (VSS), H1.3 (G), H2.3 (G), H3.3 (G), H4.3 (G), R2.1, SW1.1 ("~"), SW2.1 ("~"), SW3.2 ("~"), SW4.2 ("~"), SW5.2 ("~"), SW6.2 ("~"), SW7.2 ("~"), U1.3 (GND), U1.8 (GND), U1.13 (GND), U1.18 (GND), U1.23 (GND), U1.28 (GND), U1.33 (AGND), U1.38 (GND), U2.4 (ADDR), U2.6 (VSS), U3.6 (VSS), U4.6 (VSS), U5.2 (A), U6.2 (GND), U7.3 (GND), Z1.2 (A)
unnamed: BL5.O (Out), D1.I (In)
unnamed: BL11.I (In), BL12.I (In), BL13.I (In), BL14.I (In), U1.4 (GPIO2)
unnamed: BL11.O (Out), BL21.I (In), BL22.I (In), BL23.I (In), BL24.I (In)
unnamed: BL21.O (Out), BL31.I (In), BL32.I (In), BL33.I (In), BL34.I (In)
unnamed: BL31.O (Out), BL41.I (In), BL42.I (In), BL43.I (In), BL44.I (In)
unnamed: BL5.I (In), BL41.O (Out)
unnamed: D1.O (Out), D2.I (In)
unnamed: D2.O (Out), D3.I (In)
unnamed: D3.O (Out), D4.I (In)
unnamed: D4.O (Out), D5.I (In)
unnamed: D5.O (Out), D6.I (In)
unnamed: D6.O (Out), D7.I (In)
unnamed: D7.O (Out), D8.I (In)
unnamed: D8.O (Out), D9.I (In)
unnamed: D9.O (Out), D10.I (In)
unnamed: D10.O (Out), D11.I (In)
unnamed: D11.O (Out), D12.I (In)
unnamed: D12.O (Out), D13.I (In)
unnamed: D13.O (Out), D14.I (In)
unnamed: D14.O (Out), D15.I (In)
unnamed: D15.O (Out), D16.I (In)
unnamed: D16.O (Out), D17.I (In)
unnamed: D17.O (Out), D18.I (In)
unnamed: D18.O (Out), D19.I (In)
unnamed: D19.O (Out), D20.I (In)
unnamed: D20.O (Out), D21.I (In)
unnamed: D21.O (Out), D22.I (In)
unnamed: D22.O (Out), D23.I (In)
unnamed: D23.O (Out), D24.I (In)
unnamed: D24.O (Out), D25.I (In)
unnamed: D25.O (Out), D26.I (In)
unnamed: D26.O (Out), D27.I (In)
unnamed: D27.O (Out), D28.I (In)
unnamed: D28.O (Out), D29.I (In)
unnamed: D29.O (Out), D30.I (In)
unnamed: D30.O (Out), D31.I (In)
unnamed: D31.O (Out), D32.I (In)
unnamed: K1.1, U2.8 (ELE0)
unnamed: K2.1, U2.9 (ELE1)
unnamed: K3.1, U2.10 (ELE2)
unnamed: K4.1, U2.11 (ELE3)
unnamed: K5.1, U2.12 (LED0/ELE4)
unnamed: K6.1, U2.13 (LED1/ELE5)
unnamed: K7.1, U2.14 (LED2/ELE6)
unnamed: K8.1, U2.15 (LED3/ELE7)
unnamed: K9.1, U2.16 (LED4/ELE8)
unnamed: K10.1, U2.17 (LED5/ELE9)
unnamed: K11.1, U2.18 (LED6/ELE10)
unnamed: K12.1, U3.8 (ELE0)
unnamed: K13.1, U3.9 (ELE1)
unnamed: K14.1, U3.10 (ELE2)
unnamed: K15.1, U3.11 (ELE3)
unnamed: K16.1, U3.12 (LED0/ELE4)
unnamed: K17.1, U3.13 (LED1/ELE5)
unnamed: K18.1, U3.14 (LED2/ELE6)
unnamed: K19.1, U3.15 (LED3/ELE7)
unnamed: K20.1, U3.16 (LED4/ELE8)
unnamed: K21.1, U3.17 (LED5/ELE9)
unnamed: K22.1, U3.18 (LED6/ELE10)
unnamed: K23.1, U4.8 (ELE0)
unnamed: K24.1, U4.9 (ELE1)
unnamed: K25.1, U4.10 (ELE2)
unnamed: K26.1, U4.11 (ELE3)
unnamed: K27.1, U4.12 (LED0/ELE4)
unnamed: K28.1, U4.13 (LED1/ELE5)
unnamed: K29.1, U4.14 (LED2/ELE6)
unnamed: K30.1, U4.15 (LED3/ELE7)
unnamed: K31.1, U4.16 (LED4/ELE8)
unnamed: K32.1, U4.17 (LED5/ELE9)
unnamed: U1.35 (ADC_VREF), U5.1 (K)
unnamed: SW2.2 ("~"), U1.1 (GPIO0)
unnamed: SW1.2 ("~"), U1.2 (GPIO1)
unnamed: SW3.1 ("~"), U1.12 (GPIO9)
unnamed: SW4.1 ("~"), U1.14 (GPIO10)
unnamed: SW5.1 ("~"), U1.15 (GPIO11)
unnamed: SW6.1 ("~"), U1.16 (GPIO12)
unnamed: SW7.1 ("~"), U1.17 (GPIO13)
unnamed: U1.24 (GPIO18), U7.5 (EN)
unnamed: U1.25 (GPIO19), U7.1 (A0)
unnamed: U1.26 (GPIO20), U7.10 (A1)
unnamed: R1.1, R2.2, U1.31 (GPIO26_ADC0), U1.32 (GPIO27_ADC1), Z1.1 (K)
unnamed: R1.2, U7.8 (D)
VBUS: C9.1, U1.40 (VBUS), U6.1 (IN), U6.3 (EN)
VHall: C10.1, C11.1, C12.1, H1.1 (V), H2.1 (V), H3.1 (V), H4.1 (V), U6.5 (OUT), U7.6 (VDD)
VLED: BL5.V (VDD), BL11.V (VDD), BL12.V (VDD), BL13.V (VDD), BL14.V (VDD), BL21.V (VDD), BL22.V (VDD), BL23.V (VDD), BL24.V (VDD), BL31.V (VDD), BL32.V (VDD), BL33.V (VDD), BL34.V (VDD), BL41.V (VDD), BL42.V (VDD), BL43.V (VDD), BL44.V (VDD), C1.1, C2.1, C3.1, C4.1, C5.1, C6.1, C7.1, C8.1, D1.V (VDD), D2.V (VDD), D3.V (VDD), D4.V (VDD), D5.V (VDD), D6.V (VDD), D7.V (VDD), D8.V (VDD), D9.V (VDD), D10.V (VDD), D11.V (VDD), D12.V (VDD), D13.V (VDD), D14.V (VDD), D15.V (VDD), D16.V (VDD), D17.V (VDD), D18.V (VDD), D19.V (VDD), D20.V (VDD), D21.V (VDD), D22.V (VDD), D23.V (VDD), D24.V (VDD), D25.V (VDD), D26.V (VDD), D27.V (VDD), D28.V (VDD), D29.V (VDD), D30.V (VDD), D31.V (VDD), D32.V (VDD), U1.39 (VSYS)

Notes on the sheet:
ADDR=0x5C
ADDR=0x5A
ADDR=0x5B

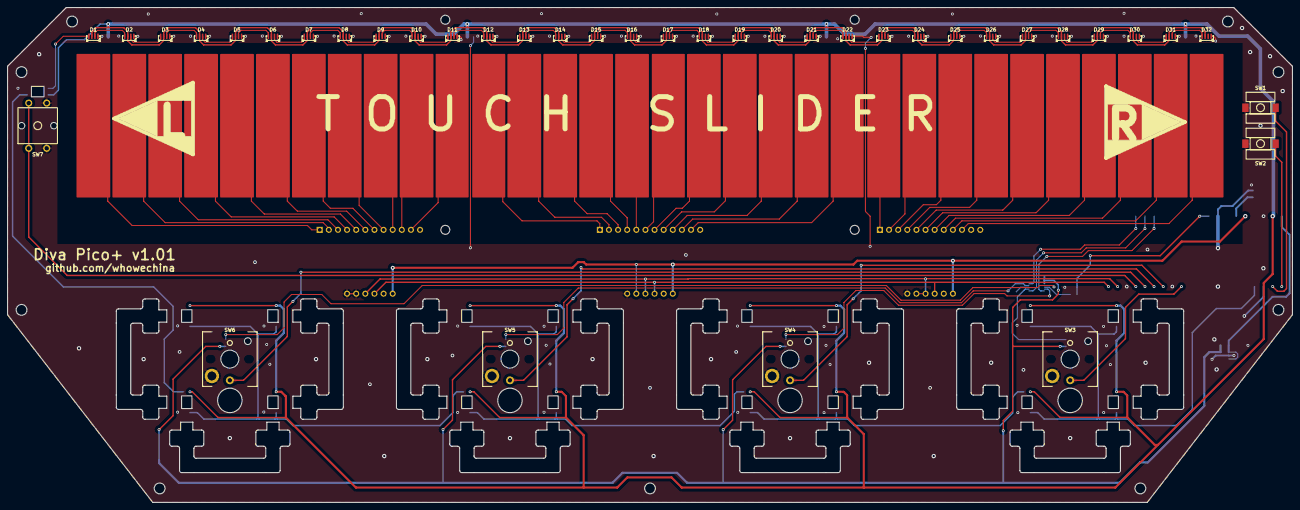
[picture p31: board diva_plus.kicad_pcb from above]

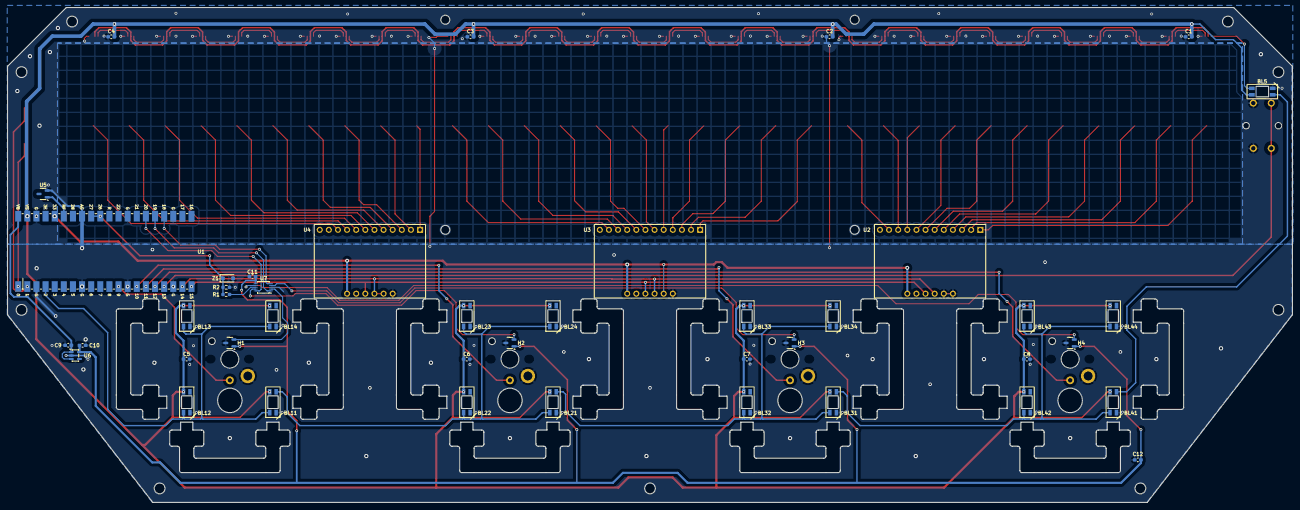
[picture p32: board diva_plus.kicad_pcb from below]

Board: 2 copper layers, 357.8 x 137.8 mm, 114 parts (43 on the bottom side), 93 nets.

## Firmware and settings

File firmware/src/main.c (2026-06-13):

/*
 * Controller Main
 * WHowe <github.com/whowechina>
 */

#include <stdlib.h>
#include <stdint.h>
#include <stdbool.h>

#include "pico/stdio.h"
#include "pico/stdlib.h"
#include "bsp/board.h"
#include "pico/multicore.h"
#include "pico/bootrom.h"

#include "hardware/gpio.h"
#include "hardware/sync.h"
#include "hardware/clocks.h"
#include "hardware/structs/ioqspi.h"
#include "hardware/structs/sio.h"

#include "tusb.h"
#include "usb_descriptors.h"

#include "board_defs.h"

#include "savedata.h"
#include "config.h"
#include "cli.h"
#include "commands.h"
#include "hid.h"

#include "slider.h"
#include "rgb.h"
#include "button.h"
#include "hebtn.h"
#include "lzfx.h"
#include "ps4key.h"
#include "gesture.h"

#define LOG_SAVE_DELAY_SEC 600

static uint16_t unified_button_read()
{
    return button_read() | hebtn_read();
}

static uint32_t touch_mask_raw(void)
{
    uint32_t mask = 0;
    int zone_num = slider_zone_num();

    for (int i = 0; i < zone_num; i++) {
        if (slider_touched(i)) {
            mask |= (1u << i);
        }
    }

    return mask;
}

static void run_lights()
{
    struct {
        int led;
        uint32_t color;
    } button_colors[7] = {
        {0, rgb32(0, 0xff, 0, false)},
        {1, rgb32(0xe0, 0x10, 0xe0, false)},
        {2, rgb32(0, 0, 0xff, false)},
        {3, rgb32(0xff, 0, 0, false)},
        {-1, 0},
        {-1, 0},
        {4, rgb32(0xf0, 0xf0, 0x00, false)},
    };

    uint64_t now = time_us_64();

    uint16_t buttons = unified_button_read();
    for (int i = 0; i < count_of(button_colors); i++) {
        if (button_colors[i].led < 0) {
            continue;
        }
        bool pressed = buttons & (1 << i);
        uint32_t shifted_color = ((now >> 17) % 3) ? 0x7f7f00 : 0x1f1f00;
        uint32_t off_color = hid_shift_activated() ? shifted_color : 0x505050;
        uint32_t color = pressed ? button_colors[i].color : off_color;
        rgb_button_color(button_colors[i].led, color);
    }

    static int rainbow_level = 0;

    int zone_num = slider_zone_num();
    uint32_t phase = ((now >> 10) / zone_num) & 0xff;
    uint32_t touch_bits = slider_touch_bits();

    if ((touch_bits) && (rainbow_level > 80)) {
        rainbow_level -= (rainbow_level > 168) ? 2 : 1;
    }
    if ((!touch_bits) && (rainbow_level < 256)) {
        rainbow_level += (rainbow_level < 168) ? 2 : 1;
    }

    for (int i = 0; i < zone_num; i++) {
        uint32_t color = rgb32_from_hsv(i * 256 / zone_num + phase, 255, rainbow_level / 2);
        rgb_slider_color(i, touch_bits & (1 << i) ? 0xffffff: color);
    }
}

static void light_update()
{
    run_lights();
    rgb_update();
}

static void core1_init()
{
    flash_safe_execute_core_init();
}

static void core1_loop()
{
    core1_init();
    while (1) {
        ps4key_job_loop();
        sleep_us(1000);
    }
}

static void core0_loop()
{
    uint64_t next_frame = time_us_64();

    while(1) {
        tud_task();

        cli_run();
    
        if (time_us_64() > LOG_SAVE_DELAY_SEC * 1000000ULL) {
            savedata_save_log();
        }

        savedata_loop();
        cli_fps_count(0);

        button_update();
        slider_update();
        hebtn_update();

        hid_update(unified_button_read(), touch_mask_raw());

        light_update();
   
        next_frame += 1000;
        sleep_until(next_frame);
    }
}

void tud_mount_cb(void)
{
    savedata_logf("usb mount");
}

void tud_umount_cb(void)
{
    savedata_logf("usb unmount");
}

void tud_suspend_cb(bool remote_wakeup_en)
{
    (void)remote_wakeup_en;
    savedata_logf("usb suspend");
}

void tud_resume_cb(void)
{
    savedata_logf("usb resume");
}

/* if certain key pressed when booting, enter update mode */
static void update_check()
{
    button_update();
    uint16_t buttons = button_read();
    if (((buttons >> 4) & 0x03) == 0x03) {
        sleep_ms(100);
        reset_usb_boot(0, 2);
        return;
    }
}

static void keymap_check()
{
    button_update();
    hebtn_update();

    uint16_t buttons = unified_button_read();
    if (buttons == 0x01) {
        diva_cfg->hid.joy_map = 0;
    } else if (buttons == 0x02) {
        diva_cfg->hid.joy_map = 1;
    } else if (buttons == 0x04) {
        diva_cfg->hid.joy_map = 2;
    } else if (buttons == 0x08) {
        diva_cfg->hid.joy_map = 3;
        diva_cfg->hid.ps4_arcade = false;
    } else if (buttons == (0x08 | 0x04)) {
        diva_cfg->hid.joy_map = 3;
        diva_cfg->hid.ps4_arcade = true;

    } else {
        return;
    }

    hid_apply_mode();
    config_changed();
}

void init()
{
    sleep_ms(50);
    set_sys_clock_khz(180000, true);

    button_init();
    update_check();

    config_init();
    savedata_init(0xca44cafe);

    slider_init();
    rgb_init();
    rgb_set_half_mode(slider_zone_num() <= 16);

    hebtn_init(diva_cfg->hall.cali_up, diva_cfg->hall.cali_down,
               diva_cfg->hall.trig_on, diva_cfg->hall.trig_off);

    keymap_check();

    gesture_init(slider_zone_num());

    board_init();
    tusb_init();
    stdio_init_all();

    ps4key_init();

    cli_init("diva_pico>", "\n   << Diva Pico Controller >>\n"
                            " https://github.com/whowechina\n\n");
    
    commands_init();
}

int main(void)
{
    init();
    multicore_launch_core1(core1_loop);
    core0_loop();
    return 0;
}

// Invoked when received GET_REPORT control request
// Application must fill buffer report's content and return its length.
// Return zero will cause the stack to STALL request
uint16_t tud_hid_get_report_cb(uint8_t itf, uint8_t report_id,
                               hid_report_type_t report_type, uint8_t *buffer,
                               uint16_t reqlen)
{
    return hid_get_report(report_id, report_type, buffer, reqlen);
}

// Invoked when received SET_REPORT control request or
// received data on OUT endpoint ( Report ID = 0, Type = 0 )
void tud_hid_set_report_cb(uint8_t itf, uint8_t report_id,
                           hid_report_type_t report_type, uint8_t const *buffer,
                           uint16_t bufsize)
{
    if (diva_runtime.hid_ps4) {
        ps4key_set_report(report_id, report_type, buffer, bufsize);
        return;
    }

    if (report_type == HID_REPORT_TYPE_OUTPUT) {
        uint8_t obuf[48];
        memcpy(obuf, buffer, bufsize);
        if (report_id == REPORT_ID_LED_SLIDER_1) {
            rgb_set_hid_slider(0, 16, obuf, true);
        } else if (report_id == REPORT_ID_LED_SLIDER_2) {
            rgb_set_hid_slider(16, 16, obuf, true);
        } else if (report_id == REPORT_ID_LED_BUTTON) {
            rgb_set_hid_button(obuf);
        }
    } else if (report_type == HID_REPORT_TYPE_FEATURE) {
        if (report_id == REPORT_ID_LED_COMPRESSED) {
            uint8_t fbuf[64];
            memcpy(fbuf, buffer, bufsize);
            uint8_t decomp[100];
            unsigned int olen = sizeof(decomp);
            if (lzfx_decompress(fbuf + 1, fbuf[0], decomp, &olen) != 0) {
                return;
            }
            if (olen < 96) {
                return;
            }
            rgb_set_hid_slider(0, 32, decomp, false);
        }
    }
}

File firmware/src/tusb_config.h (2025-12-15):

/*
 * The MIT License (MIT)
 *
 * Copyright (c) 2019 Ha Thach (tinyusb.org)
 *
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
 */

#ifndef _TUSB_CONFIG_H_
#define _TUSB_CONFIG_H_

#ifdef __cplusplus
extern "C" {
#endif

//--------------------------------------------------------------------
// COMMON CONFIGURATION
//--------------------------------------------------------------------

// defined by board.mk
#ifndef CFG_TUSB_MCU
#error CFG_TUSB_MCU must be defined
#endif

// RHPort number used for device can be defined by board.mk, default to port 0
#ifndef BOARD_DEVICE_RHPORT_NUM
#define BOARD_DEVICE_RHPORT_NUM 0
#endif

// RHPort max operational speed can defined by board.mk
// Default to Highspeed for MCU with internal HighSpeed PHY (can be port
// specific), otherwise FullSpeed
#ifndef BOARD_DEVICE_RHPORT_SPEED
#if (CFG_TUSB_MCU == OPT_MCU_LPC18XX || CFG_TUSB_MCU == OPT_MCU_LPC43XX ||   \
     CFG_TUSB_MCU == OPT_MCU_MIMXRT10XX || CFG_TUSB_MCU == OPT_MCU_NUC505 || \
     CFG_TUSB_MCU == OPT_MCU_CXD56)
#define BOARD_DEVICE_RHPORT_SPEED OPT_MODE_HIGH_SPEED
#else
#define BOARD_DEVICE_RHPORT_SPEED OPT_MODE_FULL_SPEED
#endif
#endif

// Device mode with rhport and speed defined by board.mk
#if BOARD_DEVICE_RHPORT_NUM == 0
#define CFG_TUSB_RHPORT0_MODE (OPT_MODE_DEVICE | BOARD_DEVICE_RHPORT_SPEED)
#elif BOARD_DEVICE_RHPORT_NUM == 1
#define CFG_TUSB_RHPORT1_MODE (OPT_MODE_DEVICE | BOARD_DEVICE_RHPORT_SPEED)
#else
#error "Incorrect RHPort configuration"
#endif

#ifndef CFG_TUSB_OS
#define CFG_TUSB_OS OPT_OS_NONE
#endif

// CFG_TUSB_DEBUG is defined by compiler in DEBUG build
// #define CFG_TUSB_DEBUG           0

/* USB DMA on some MCUs can only access a specific SRAM region with restriction
 * on alignment. Tinyusb use follows macros to declare transferring memory so
 * that they can be put into those specific section. e.g
 * - CFG_TUSB_MEM SECTION : __attribute__ (( section(".usb_ram") ))
 * - CFG_TUSB_MEM_ALIGN   : __attribute__ ((aligned(4)))
 */
#ifndef CFG_TUSB_MEM_SECTION
#define CFG_TUSB_MEM_SECTION
#endif

#ifndef CFG_TUSB_MEM_ALIGN
#define CFG_TUSB_MEM_ALIGN __attribute__((aligned(4)))
#endif

//--------------------------------------------------------------------
// DEVICE CONFIGURATION
//--------------------------------------------------------------------

#ifndef CFG_TUD_ENDPOINT0_SIZE
#define CFG_TUD_ENDPOINT0_SIZE 64
#endif

//------------- CLASS -------------//
#define CFG_TUD_HID 3
#define CFG_TUD_CDC 2
#define CFG_TUD_MSC 0
#define CFG_TUD_MIDI 0
#define CFG_TUD_VENDOR 0

#define CFG_TUD_VENDOR            0

// HID buffer size Should be sufficient to hold ID (if any) + Data
#define CFG_TUD_HID_EP_BUFSIZE    64

// CDC FIFO size of TX and RX
#define CFG_TUD_CDC_RX_BUFSIZE   (TUD_OPT_HIGH_SPEED ? 512 : 128)
#define CFG_TUD_CDC_TX_BUFSIZE   (TUD_OPT_HIGH_SPEED ? 512 : 128)

// CDC Endpoint transfer buffer size, more is faster
#define CFG_TUD_CDC_EP_BUFSIZE   (TUD_OPT_HIGH_SPEED ? 512 : 128)

#ifdef __cplusplus
}
#endif

#endif /* _TUSB_CONFIG_H_ */

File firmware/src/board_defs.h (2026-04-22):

/*
 * Diva Controller Board Definitions
 * WHowe <github.com/whowechina>
 */

#if defined BOARD_DIVA_PICO

#define I2C_PORT i2c1
#define I2C_SDA 14
#define I2C_SCL 15
#define I2C_FREQ 433*1000

#define RGB_PIN 2
#define RGB_ORDER GRB // or RGB

#define RGB_BUTTON_MAP { 3, 2, 1, 0, 4 }
#define BUTTON_DEF { 12, 11, 10, 9, 1, 0, 13 } // Main * 4, R1, R2, L1

/* A0, A1, A2, ... */
#define HALL_KEY_MUX_ADDRS { 19, 20 }
#define HALL_KEY_MUX_MAP { 3, 2, 1, 0 }
#define HALL_KEY_MUX_EN 18
#define HALL_KEY_ADC_CHN 0

#else

#endif

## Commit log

2023-12-16 PCB work just started
    [Credit Button Assy (Groovy).step, EVQ-P1D05M.stp, J 2835.step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]
2023-12-17 PCB layout done
    [SKSTAAE010.STEP, b3f-4000.stp, diva_main.kicad_pcb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]
2023-12-17 PCB v1.0 ready
    [diva_main.kicad_pcb, diva_main.kicad_sch]
2023-12-31 Nintendo Switch works too
2024-01-01 To publish
    [diva_pico_base.stl.stl, diva_pico_buttons_fixed_42.3mf, diva_pico_buttons_fixed_48.3mf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]
2024-07-15 Cross-reference to new Groove Pico
2025-02-12 Fix file names
    [diva_pico_base.stl, diva_pico_base.stl.stl, diva_pico_cover_base.stl]
2025-02-14 Flowing rainbow lights
2025-02-14 Improved housing
    [diva_pico_base.stl, diva_pico_cover_42.3mf, diva_pico_cover_42.3mf.stl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]
2025-02-14 PCB v1.1 (minor optimization)
    [diva_main.kicad_pcb, diva_main.kicad_sch]
2025-02-14 More screws in housing
    [diva_pico_base.stl, diva_pico_cover_42.3mf, diva_pico_cover_48.3mf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]
2025-02-28 Fix filter and sense command
2025-03-02 Cross-ref to Ju Pico
2025-03-12 Update base for Pico clearance
    [diva_pico_base.stl]
2025-03-22 Remove USB pin soldering warning
2025-03-22 Update PCB vendor lines in guide
2025-03-22 Update base to reduce bend
    [diva_pico_base.stl]
2025-03-27 Remove unnessary options, focus on best one
    [diva_pico_base.stl, diva_pico_button_combo.3mf, diva_pico_buttons_fixed_42.3mf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]
2025-04-21 Fix diva base USB hole position
    [diva_pico_base.stl]
2025-05-02 Stronger button platform
    [diva_pico_button_combo.3mf]
2025-08-25 Keymap setting for Switch|Steam|Arcade
2025-08-26 Fix and clean-up lights
    [board_defs.h, main.c]
2025-08-26 Better button light color
2025-08-26 Stronger panel screw holes
    [diva_pico_panel.3mf]
2025-10-14 Finetune button seat
    [diva_pico_button_combo.3mf]
2025-12-07 Rename old PCB as pico
    [Credit Button Assy (Groovy).step, EVQ-P1D05M.stp, J 2835.step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]
2025-12-07 Start PCB work of diva plus
    [Credit Button Assy (Groovy).step, Diva Pico+ - PCB EdgeCut.dxf, EVQ-P1D05M.stp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]
2025-12-12 Firmware support for Diva Pico+
2025-12-13 Separate slider and button level
2026-01-07 Diva Pico+ files
    [Button+_Choc_V1_Combo.3mf, Button+_Choc_V2_Combo.3mf, Button+_Combo.3mf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]
2026-01-09 Fix cb re-entry buffer overwrite
    [main.c]
2026-01-30 Finetune square sign
    [Button+_Choc_V1_Combo.3mf, Button+_Choc_V2_Combo.3mf, Button+_Combo.3mf]
2026-02-11 Minor footprint and silkscreen finetune
    [diva_plus.kicad_pcb]
2026-03-03 Better base thread holes
2026-04-06 Diva button finetune (lower limiter/ears)
    [diva_pico_button_combo.3mf]
2026-04-13 Side buttons mapped to HAT up/down in PS4 mode
2026-04-14 PS4 authentication (not working yet)
    [main.c]
2026-04-15 Remove pwm lib
2026-04-17 Fix slider breath effect
    [main.c]
2026-05-22 Fix PS mode not working issue (introduced earlier)
    [main.c]
2026-06-04 Diva pico button base finetune
    [diva_pico_button_combo.3mf]
2026-06-13 Fix LED logic
2026-06-24 Update guide for Diva Pico+
